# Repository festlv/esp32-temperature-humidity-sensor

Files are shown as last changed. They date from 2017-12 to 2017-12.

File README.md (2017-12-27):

# ESP32 environment sensor

This project encompasses hardware and firmware for a WiFi-enabled temperature and humidity sensor.
It has a battery life of ~3 months on a single lithium-ion battery (3000mAh), by reporting temperature and humidity every 15 minutes.

Documentation is a little bit sparse, as this project is for my personal use.

# Recommended hardware changes

After rev1 hardware was built, I realized a few things:
* Either don't use resistor divider to measure battery voltage, or connect it only when awake via transistor (it consumes ~25uA).
* Change MIC5504 voltage regulator to one with less leakage current- it consumes ~40uA.

# Pictures
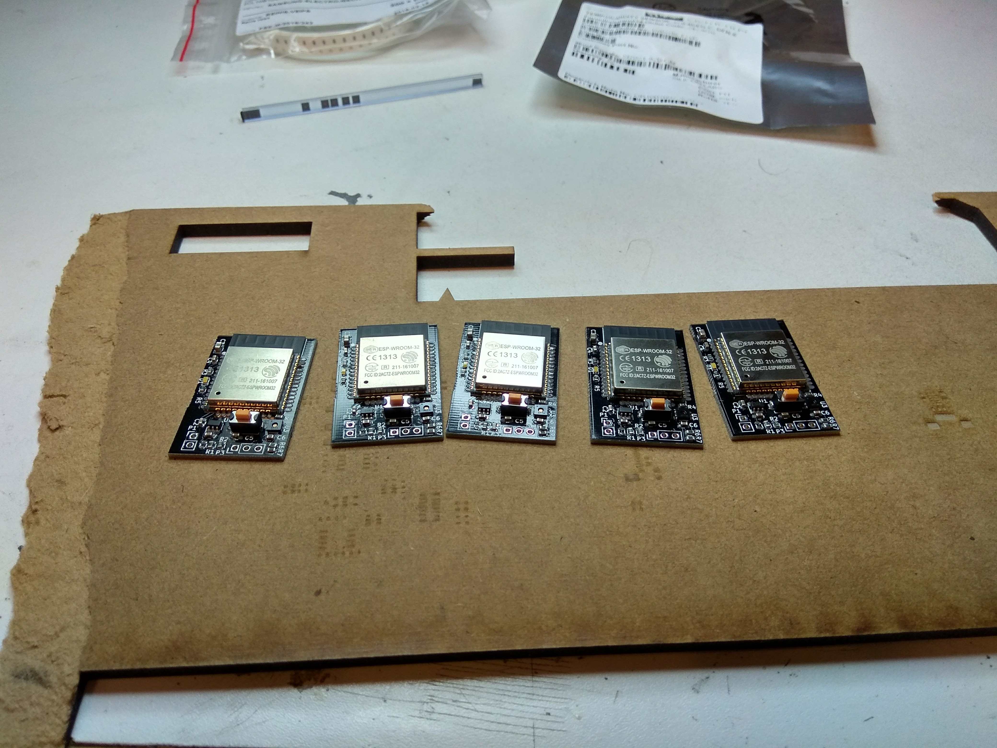
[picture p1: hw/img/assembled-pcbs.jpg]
PCBs assembled in reflow oven

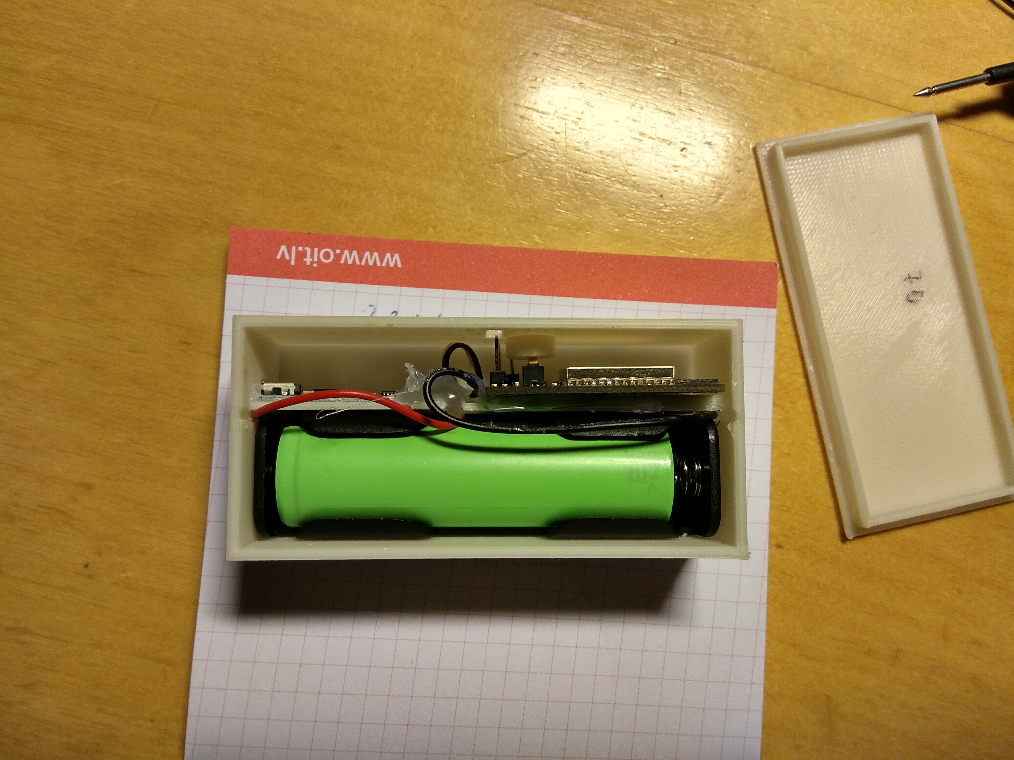
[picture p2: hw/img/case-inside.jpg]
3D printed case with components

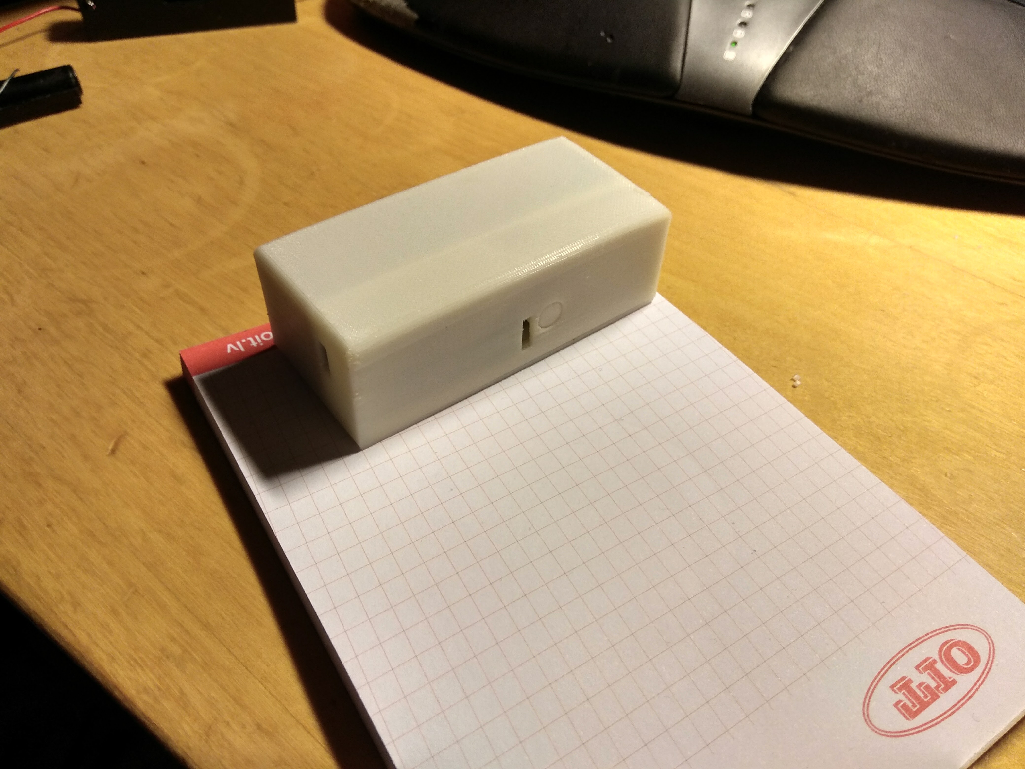
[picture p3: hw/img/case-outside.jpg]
Outside of 3D printed case


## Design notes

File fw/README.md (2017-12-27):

# ESP-Environment

Build: `source ~/Sync/esp32/environment-setup && make -j10`

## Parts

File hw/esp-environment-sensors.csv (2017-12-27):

Refs | datasheet | footprint | value | MPN | Manufacturer | VPN | Vendor
C1 |  | Capacitors_SMD:C_0603 | 1uF
C2 |  | Capacitors_SMD:C_0603 | 1uF
C3 |  | Capacitors_SMD:C_0805 | 22uF
C4 |  | Capacitors_SMD:C_0603 | 0.1uF
C5 |  | Capacitors_SMD:C_0603 | 0.1uF
C6 |  | Capacitors_SMD:C_0603 | 1uF
D1 |  | Diodes_SMD:D_0603 | LED
J1 |  | solder_bridges:SB_NC | SB_NC
P1 |  | Pin_Headers:Pin_Header_Straight_1x02_Pitch2.54mm | PWR
P2 |  | pin_headers_1.27mm:Pin_Header_1.27mm_2x5 | CONN_JTAG
P3 |  | Pin_Headers:Pin_Header_Straight_1x03_Pitch2.54mm | DBG
R1 |  | Resistors_SMD:R_0603 | 47K
R2 |  | Resistors_SMD:R_0603 | 100K
R3 |  | Resistors_SMD:R_0603 | 10K
R4 |  | Resistors_SMD:R_0603 | 10K
R5 |  | Resistors_SMD:R_0603 | 220R
R6 |  | Resistors_SMD:R_0603 | 2K2
R7 |  | Resistors_SMD:R_0603 | 2K2
SW1 |  | Buttons_Switches_SMD:SW_SPST_EVQPE1 | BTN0 | EVQ-PE104K | Panasonic | 667-EVQ-PE104K | Mouser
U1 |  | TO_SOT_Packages_SMD:SOT-23-5 | MIC5504 | MIC5504-3.3YM5-TR | Microchip | 998-MIC5504-3.3YM5TR | Mouser
U2 |  | ESP32-footprints-Lib:ESP32-WROOM | ESP32-WROOM
U3 |  | Housings_DFN_QFN:DFN-6-1EP_3x3mm_Pitch0.95mm | Si7021 | SI7021-A20-GM1R | Silicon Labs | 634-SI7021-A20-GM1R | Mouser

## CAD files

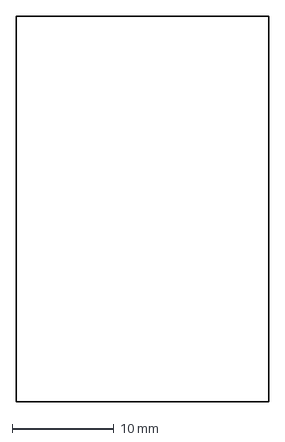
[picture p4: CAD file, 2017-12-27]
hw/out/esp-environment-sensors-Edge.Cuts.dxf
24.8 x 37.8 mm

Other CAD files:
hw/out/esp-environment-sensors-F.Paste.dxf

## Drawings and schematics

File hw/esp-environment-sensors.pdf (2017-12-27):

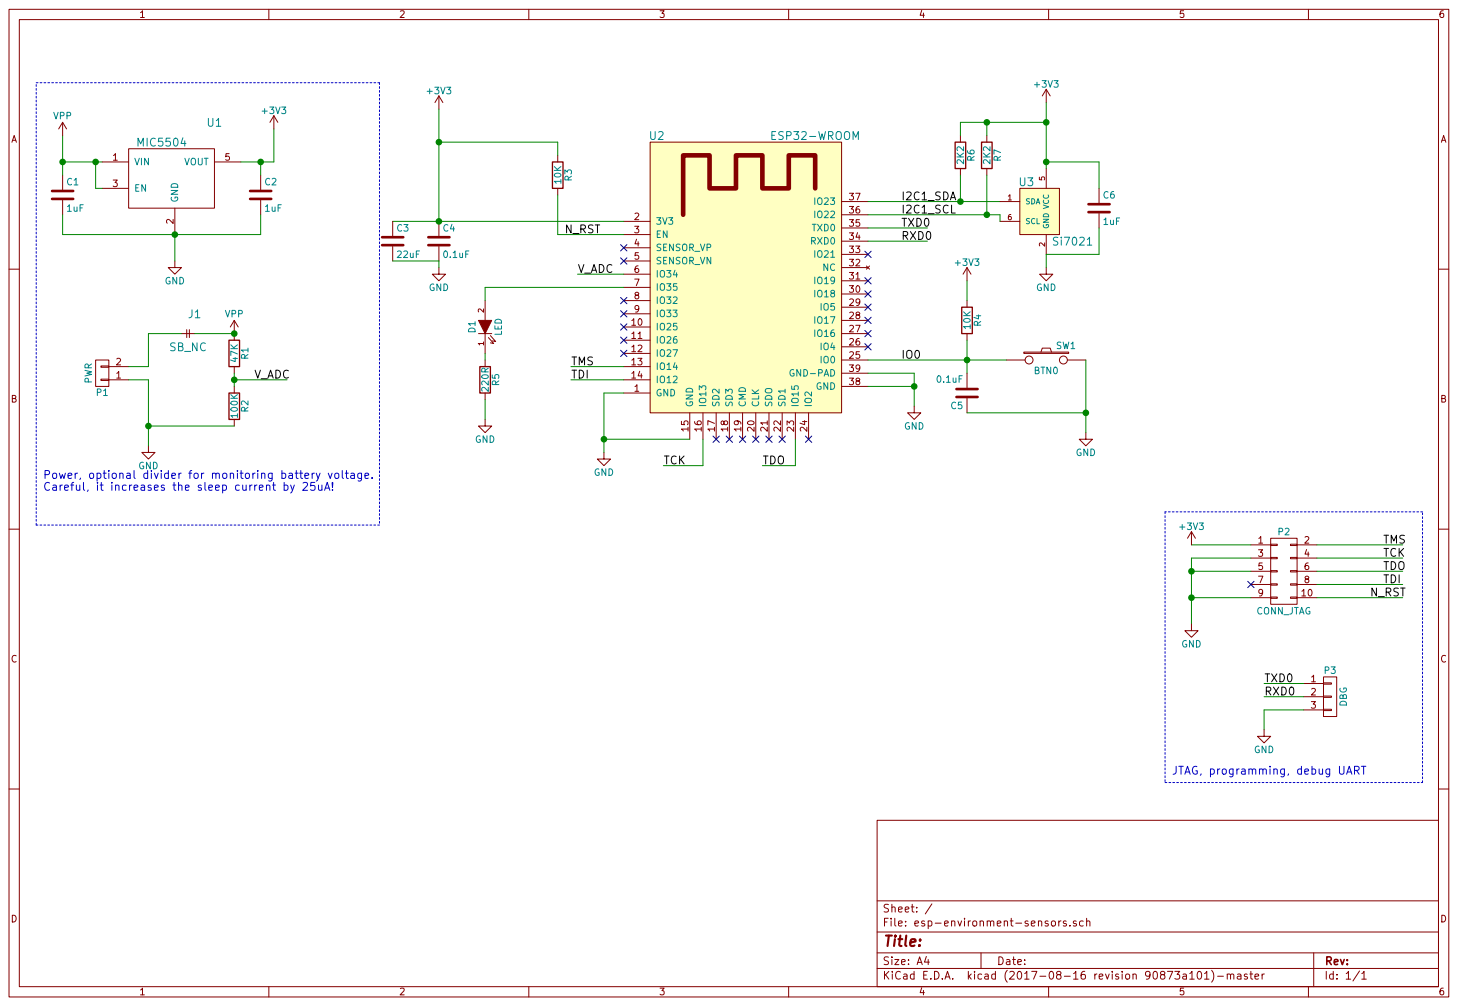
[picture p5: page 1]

Power, optional divider for monitoring battery voltage.

5 | 6 | TDO
7 | 8 | TDI N_RST

JTAG, programming, debug UART

File: esp-environment-sensors.sch Sheet: /
Id: 1/1 Title:

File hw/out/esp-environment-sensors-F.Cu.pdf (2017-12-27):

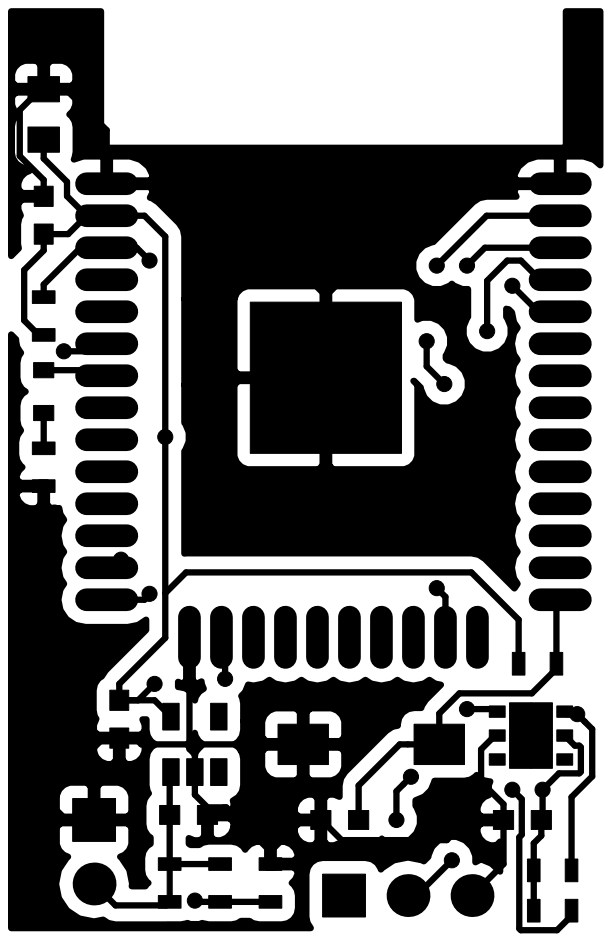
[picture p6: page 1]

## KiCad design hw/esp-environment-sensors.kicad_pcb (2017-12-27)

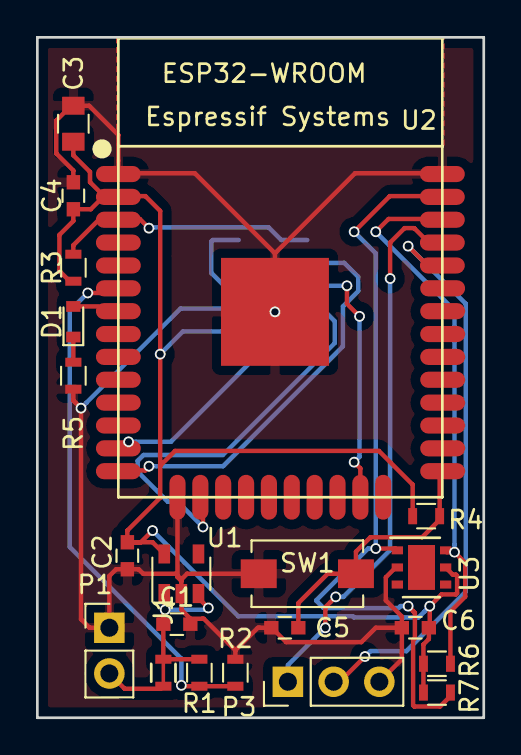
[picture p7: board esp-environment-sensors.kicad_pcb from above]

Board: 2 copper layers, 24.8 x 37.8 mm, 22 parts (1 on the bottom side), 17 nets.

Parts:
C1, C2, C6: 1uF; C_0603
C3: 22uF; C_0805
C4, C5: 0.1uF; C_0603
D1: LED; D_0603
J1: SB_NC
P1: PWR; Pin_Header_Straight_1x02_Pitch2.54mm
P2: CONN_JTAG; Pin_Header_1.27mm_2x5
P3: DBG; Pin_Header_Straight_1x03_Pitch2.54mm
R1: 47K; R_0603
R2: 100K; R_0603
R3, R4: 10K; R_0603
R5: 220R; R_0603
R6, R7: 2K2; R_0603
SW1: BTN0; SW_SPST_EVQPE1
U1: MIC5504; SOT-23-5
U2: ESP32-WROOM
U3: Si7021; DFN-6-1EP_3x3mm_Pitch0.95mm

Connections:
+3V3: C2.1, C3.1, C4.1, C6.1, P2.1, R3.1, R4.1, R6.1, R7.1, U1.5, U2.2, U3.5
/I2C1_SCL: R7.2, U2.36, U3.6
/I2C1_SDA: R6.2, U2.37, U3.1
/IO0: C5.2, R4.2, SW1.1, U2.25
/N_RST: P2.10, R3.2, U2.3
/RXD0: P3.2, U2.34
/TCK: P2.4, U2.16
/TDI: P2.8, U2.14
/TDO: P2.6, U2.23
/TMS: P2.2, U2.13
/TXD0: P3.1, U2.35
/V_ADC: R1.2, R2.1, U2.6
GND: C1.2, C2.2, C3.2, C4.2, C5.1, C6.2, P1.1, P2.3, P2.5, P2.9, P3.3, R2.2, R5.2, SW1.2, U1.2, U2.1, U2.15, U2.38, U2.39, U3.2
unnamed: D1.1, R5.1
unnamed: D1.2, U2.7
unnamed: J1.2, P1.2
VPP: C1.1, J1.1, R1.1, U1.1, U1.3

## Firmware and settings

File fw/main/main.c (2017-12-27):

/* ESP32 temperature and humidity sensor

   This example code is in the Public Domain (or CC0 licensed, at your option.)

   Unless required by applicable law or agreed to in writing, this
   software is distributed on an "AS IS" BASIS, WITHOUT WARRANTIES OR
   CONDITIONS OF ANY KIND, either express or implied.
*/
#include <stdio.h>
#include "freertos/FreeRTOS.h"
#include "freertos/task.h"
#include "freertos/event_groups.h"
#include "driver/gpio.h"
#include "driver/i2c.h"
#include "sdkconfig.h"
#include "esp_wifi.h"
#include "esp_log.h"
#include "esp_system.h"
#include "driver/adc.h"
#include "esp_event_loop.h"
#include "esp_deep_sleep.h"
#include "influx.h"
#include "si7021.h"

static const char *TAG = "sens";

static void led_blink(void)
{
    gpio_set_level(CONFIG_LED_GPIO_NUM, 1);
    vTaskDelay(10 / portTICK_PERIOD_MS);
    gpio_set_level(CONFIG_LED_GPIO_NUM, 0);
}

bool read_done = false;
float temperature_reading, humidity_reading, battery_voltage_reading;

#define I2C_MASTER_PORT 1

static void i2c_init(void)
{
    i2c_config_t conf;
    conf.mode = I2C_MODE_MASTER;
    conf.sda_io_num = 23;
    conf.sda_pullup_en = 0;
    conf.scl_io_num = 22;
    conf.scl_pullup_en = 0;
    conf.master.clk_speed = 400000;
    i2c_param_config(I2C_MASTER_PORT, &conf);
    uint32_t rxbuf_len = 0;
    uint32_t txbuf_len = 0;
    i2c_driver_install(I2C_MASTER_PORT, conf.mode, rxbuf_len, txbuf_len, 0);
}

static void start_sleep(void)
{
    esp_deep_sleep_enable_timer_wakeup(1000000LL * CONFIG_WAKEUP_INTERVAL);
    esp_deep_sleep_pd_config(ESP_PD_DOMAIN_RTC_PERIPH, ESP_PD_OPTION_AUTO);
    esp_deep_sleep_enable_ext0_wakeup(CONFIG_WAKEUP_GPIO_NUM, CONFIG_WAKEUP_GPIO_LEVEL);
    ESP_LOGI(TAG, "entering deep sleep mode");
    esp_deep_sleep_start();
}

void timer_callback(TimerHandle_t timer)
{
    (void)timer;
    ESP_LOGI(TAG, "sleep from timer");
    start_sleep();
}

char mac_str[32];

void user_publish(void)
{
    uint8_t mac[6];
    esp_efuse_mac_get_default(mac);

    snprintf(mac_str, sizeof(mac_str), "%02x-%02x-%02x-%02x-%02x-%02x",
            mac[0], mac[1], mac[2], mac[3], mac[4], mac[5]);
    
    char temp_str[16];
    char hum_str[16];
    char volt_str[16];

    snprintf(temp_str, sizeof(temp_str), "%.2f", temperature_reading);
    snprintf(hum_str, sizeof(hum_str), "%.2f", humidity_reading);
    snprintf(volt_str, sizeof(volt_str), "%.2f", battery_voltage_reading);
    ESP_LOGI(TAG, "publishing measurements");
    publish_measurements(mac_str, hum_str, temp_str, volt_str);
    ESP_LOGI(TAG, "measurements published");
    start_sleep();
}

static esp_err_t event_handler(void *ctx, system_event_t *event)
{
    switch(event->event_id) {
    case SYSTEM_EVENT_STA_START:
	ESP_LOGI(TAG, "SYSTEM_EVENT_STA_START");
	ESP_ERROR_CHECK(esp_wifi_connect());
	break;
    case SYSTEM_EVENT_STA_GOT_IP:
    {
	ESP_LOGI(TAG, "SYSTEM_EVENT_STA_GOT_IP");
	ESP_LOGI(TAG, "got ip:%s\n",
		ip4addr_ntoa(&event->event_info.got_ip.ip_info.ip));

    led_blink();

    user_publish();

    }
        break;
    case SYSTEM_EVENT_STA_DISCONNECTED:
	ESP_LOGI(TAG, "SYSTEM_EVENT_STA_DISCONNECTED");
    //start_sleep();
	ESP_ERROR_CHECK(esp_wifi_connect());
	break;
    default:
        break;
    }
    return ESP_OK;
}




static void wifi_init(void)
{
    tcpip_adapter_init();
    ESP_ERROR_CHECK(esp_event_loop_init(event_handler, NULL));
    wifi_init_config_t cfg = WIFI_INIT_CONFIG_DEFAULT();
    ESP_ERROR_CHECK(esp_wifi_init(&cfg));
    wifi_config_t wifi_config = {
	.sta = {
	    .ssid = CONFIG_WIFI_SSID,
	    .password = CONFIG_WIFI_PASSWORD
	},
    };
    ESP_ERROR_CHECK(esp_wifi_set_mode(WIFI_MODE_STA));
    ESP_ERROR_CHECK(esp_wifi_set_config(ESP_IF_WIFI_STA, &wifi_config));
    ESP_ERROR_CHECK(esp_wifi_start());
}
TimerHandle_t timer;
void app_main()
{
    gpio_pad_select_gpio(CONFIG_LED_GPIO_NUM);
    gpio_set_direction(CONFIG_LED_GPIO_NUM, GPIO_MODE_OUTPUT);
    gpio_set_level(CONFIG_LED_GPIO_NUM, 0);
    
    adc1_config_width(ADC_WIDTH_12Bit);
    adc1_config_channel_atten(ADC1_CHANNEL_6,ADC_ATTEN_0db);
    int adc_counts = adc1_get_voltage(ADC1_CHANNEL_6);
    battery_voltage_reading  = ((adc_counts / 4096.0f) * 3.3f) / 0.659f;

    led_blink();

    i2c_init();
    vTaskDelay(80 / portTICK_PERIOD_MS);
    bool ret = si7021_read(I2C_MASTER_PORT, &humidity_reading, &temperature_reading);
    if (ret)
    {
        ESP_LOGI(TAG,"humidity=%.2f%%, temperature=%.2fdegC",
                humidity_reading, temperature_reading);
        read_done = true;
        wifi_init();
    } else {
        ESP_LOGE(TAG, "could not read si7021");
        read_done = false;
        start_sleep();
    }
    timer = xTimerCreate("sleeptimer", 5000 / portTICK_PERIOD_MS, false, 0, timer_callback);
    xTimerStart(timer, 0);
}

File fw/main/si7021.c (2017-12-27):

#include "si7021.h"

#include "esp_log.h"

static const char *TAG = "si7021";

#define SI7021_ADDR (0x40)
#define SI7021_MEASURE_HUM_NO_HOLD  (0xF5)
#define SI7021_READ_TEMPERATURE     (0xE0)
#define SI7021_MEASURE_TEMP_NO_HOLD (0xF3)

bool si7021_read(i2c_port_t i2c_num, float* humidity, float* temperature)
{
    //start humidity conversion
    i2c_cmd_handle_t cmd = i2c_cmd_link_create();
    i2c_master_start(cmd);
    i2c_master_write_byte(cmd, SI7021_ADDR << 1 | I2C_MASTER_WRITE, 1);
    i2c_master_write_byte(cmd, SI7021_MEASURE_HUM_NO_HOLD, 1);
    i2c_master_stop(cmd);

    int ret = i2c_master_cmd_begin(i2c_num, cmd, 100 / portTICK_PERIOD_MS);
    i2c_cmd_link_delete(cmd);

    if (ret == ESP_FAIL)
    {
        ESP_LOGE(TAG, "failed to start humidity conversion");
        return false;
    }

    //wait for conversion end
    vTaskDelay(30 / portTICK_PERIOD_MS);
    
    //read humidity value
    cmd = i2c_cmd_link_create();
    i2c_master_start(cmd);
    i2c_master_write_byte(cmd, SI7021_ADDR << 1 | I2C_MASTER_READ, 1);
    uint8_t hum_low, hum_high;
    i2c_master_read_byte(cmd, &hum_high, 1);
    i2c_master_read_byte(cmd, &hum_low, 0);
    i2c_master_stop(cmd);

    ret = i2c_master_cmd_begin(i2c_num, cmd, 10 / portTICK_PERIOD_MS);
    i2c_cmd_link_delete(cmd);

    if (ret == ESP_FAIL)
    {
        ESP_LOGE(TAG, "failed to read humidity result");
        return false;
    }
    //convert humidity according to formula in datasheet
    int32_t hum = ((int32_t)hum_high) << 8 | hum_low;

    *humidity = (125.0f * hum) / (65536.0f) - 6.0f;
    
    //start temperature conversion
    //reading temperature associated with previous conversion was quite erratic
    cmd = i2c_cmd_link_create();
    i2c_master_start(cmd);
    i2c_master_write_byte(cmd, SI7021_ADDR << 1 | I2C_MASTER_WRITE, 1);
    i2c_master_write_byte(cmd, SI7021_MEASURE_TEMP_NO_HOLD, 1);
    i2c_master_stop(cmd);

    ret = i2c_master_cmd_begin(i2c_num, cmd, 10 / portTICK_PERIOD_MS);
    i2c_cmd_link_delete(cmd);
    if (ret == ESP_FAIL)
    {
        ESP_LOGE(TAG, "failed to start temperature conversion");
        return false;
    }
 
    //wait for conversion end
    vTaskDelay(15 / portTICK_PERIOD_MS);
 
    cmd = i2c_cmd_link_create();
    i2c_master_start(cmd);
    uint8_t temp_low, temp_high;
    i2c_master_write_byte(cmd, SI7021_ADDR << 1 | I2C_MASTER_READ, 1);
    i2c_master_read_byte(cmd, &temp_high, 1);
    i2c_master_read_byte(cmd, &temp_low, 0);
    i2c_master_stop(cmd);

    ret = i2c_master_cmd_begin(i2c_num, cmd, 10 / portTICK_PERIOD_MS);
    i2c_cmd_link_delete(cmd);

    if (ret == ESP_FAIL)
    {
        ESP_LOGE(TAG, "failed to read temperature measurement");
        return false;
    }
    int32_t temp = ((int32_t)temp_high) << 8 | temp_low;

    *temperature = ((175.72f * temp) / 65536.0f) - 46.85f;

    return true;
}
